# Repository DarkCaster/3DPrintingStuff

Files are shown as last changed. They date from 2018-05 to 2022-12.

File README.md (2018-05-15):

# My stuff for 3D printing

Projects (in subdirectories) use CC-BY-SA-4.0 license if not explicitly stated.

Directory layout:

### Anet_E10_X_BeltLock

Custom X-axis belt locks for better belt tensioning for Anet E10 3D-printer.
Please use ABS filament when printing it (or any other strong and durable material that will endure high static\dynamic stretching forces and high temperatures).
For use with this tensioning mechanism: https://www.thingiverse.com/thing:2482051

### NEMA17_GearedExtruderDrive

Simple NEMA17 geared bowden extruder drive with 6:1 gear ratio (work in progress).

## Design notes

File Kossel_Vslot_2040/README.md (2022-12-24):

Based on following work by Loong Jin Chow:
https://www.thingiverse.com/thing:749151

Changes:
- ported to newer MCAD version used in my repo
- fixed minor errors
- vslot screw-holes changed to M4, minor fix for motor screws
- top-corner updated to use M3 bolt with short thread for pulley axis

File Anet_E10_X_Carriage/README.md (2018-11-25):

# Improved X Carriage for Anet E10

Based on this drawing: https://www.thingiverse.com/thing:2833791

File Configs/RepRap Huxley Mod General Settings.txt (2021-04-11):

Printer Settings:

X: 163
Y: 167
Z: 115

Shape: Rect
X: Origin at center
V: Heated bed

//TODO: measure
Xmin: 25
Ymin: 45
Xmax: 35
Ymax: 20

GCODE Flavor: Marlin

Extruder 1:

Nozzle: 0.4
Material diameter: 1.75
Offsets: X=0, Y=0

//I: Skew factor = 0.0052805446815000160049047295274249
//J: Skew factor = -0.0013505025366120323223467769579997
//K: Skew factor = -0.0028104139251266379434524012026486
//M852 I0.00528054 J-0.0013505 K-0.00281041

M852 I0.001577 J0.000266 K-0.001529

Start GCODE (MBL):

M300 P200
M0 P300
M300 P200
M0 P300
M300 P200
M0 P300
M0 Check clearance!
G90 ;absolute positioning
G28 ;Home
M900 K0.5 ;set linear advance factor
M420 S1 ;enable bed-leveling
M420 Z0.75 ;enable and set z fade value
G92 E0 ;zero the extruded length
G1 F200 E10 ;extrude 10mm of feed stock
G92 E0 ;zero the extruded length again

End GCODE (MBL):

M104 S0 ;disable hotend heater
M140 S0 ;disable bed heater
G91 ;relative positioning
G1 E-3 F300 ;retract the filament a bit
G1 Z+5 E-3 X-20 Y-20 F6000 ;move Z up and retract filament even more
G90 ;absolute positioning
G28 X Y ;home the X and y axes
M84 ;steppers off
M420 Z0 ;disable bed-leveling z fade
M420 S0 ;disable bed-leveling

Start GCODE (UBL):

G90 ;absolute positioning
G28 ;Home
G29 A1 ;enable UBL
G29 L1 ;load UBL mesh 1
G29 F0.75 ;set UBL z fade value
G92 E0 ;zero the extruded length
G1 F200 E10 ;extrude 10mm of feed stock
G92 E0 ;zero the extruded length again

End GCODE (UBL):

M104 S0 ;disable hotend heater
M140 S0 ;disable bed heater
G91 ;relative positioning
G1 E-3 F300 ;retract the filament a bit
G1 Z+5 E-3 X-20 Y-20 F6000 ;move Z up and retract filament even more
G90 ;absolute positioning
G28 ;home
M84 ;steppers off
G29 A0 ;disable UBL

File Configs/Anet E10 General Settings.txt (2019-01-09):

Printer Settings:

X: 220
Y: 270
Z: 250 (300)

Shape: Rect
X: Origin at center
V: Heated bed

Xmin: 25
Ymin: 45
Xmax: 35
Ymax: 20

GCODE Flavor: Marlin

Extruder 1:

Nozzle: 0.4
Material diameter: 1.75
Offsets: X=0, Y=0

Skew correction
//M852 I-0.00125085 J0.00103114 K0.00283084
M852 I-0.00125085 J0.00210749 K0.00283084

Start GCODE:

G90 ;absolute positioning
G28 ;Home
M900 K0.5 ;set linear advance factor
M420 S1 ;enable bed-leveling
M420 Z0.75 ;enable and set z fade value
G1 Z15.0 F6000 ;Move the platform down 15mm
G92 E0 ;zero the extruded length
G1 F200 E10 ;extrude 10mm of feed stock
G92 E0 ;zero the extruded length again

End GCODE:

M104 S0 ;disable hotend heater
M140 S0 ;disable bed heater
G91 ;relative positioning
G1 E-3 F300 ;retract the filament a bit
G1 Z+5 E-3 X-20 Y-20 F6000 ;move Z up and retract filament even more
G90 ;absolute positioning
G28 X Y ;home the X and y axes
M84 ;steppers off
M420 Z0 ;disable bed-leveling z fade
M420 S0 ;disable bed-leveling

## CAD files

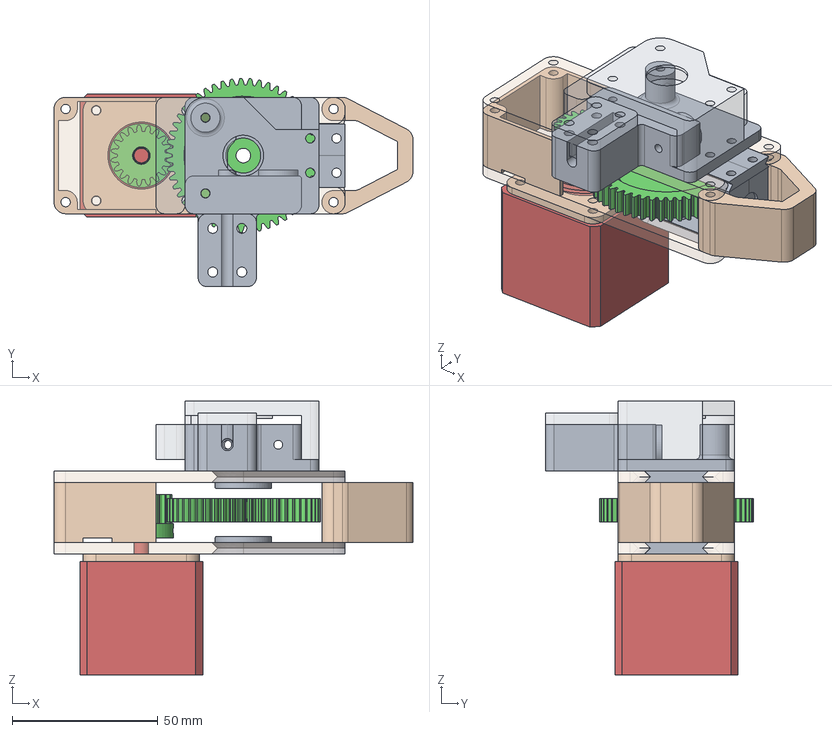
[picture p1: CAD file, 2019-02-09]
GearedExtruderDrive_V2/DriveAssembly_Variant1.FCStd
123.3 x 71.5 x 94.0 mm
FrameBottom
NEMA17Spacer
Nema17_Motor
FrontStand_H20.5mm
FrameTop
BackStand_H20.5mm
SmallGear_D5.4mm+M2.5
DriveBase_Tight_NoFitting
DriveBase_Fitting_Clamp
DriveIdler_623zz_Tight
DriveIdler_Cover_625zz
IdlerPart_625zz_Bottom
IdlerPart_625zz_Top
IdlerStand_H20.5mm
LargeGear_M5_H8mm_ClipH4.6mm_001

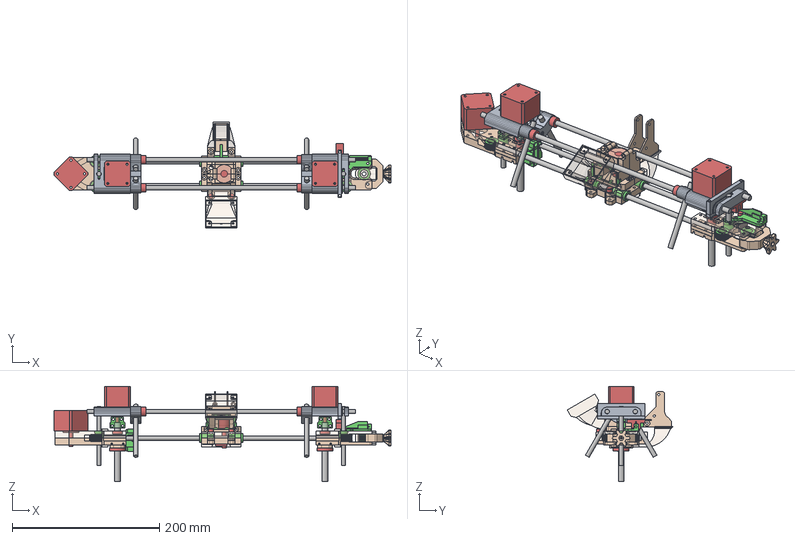
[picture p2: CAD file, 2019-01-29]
RepRap_Huxley_CustomParts/XZAxis_Assembly_A2PlusAddon.FCStd
457.6 x 143.3 x 129.0 mm
RightXEndHalf_Bottom
RightXEndHalf_Top
RightXEnd_TensionerStand
RightXEnd_TensionerKnob
RightXEnd_TensionerIdler
BeltPulley_2x685zz_FCGearAddon
Right_BeltPulley_2x623zz_FCGearAddon
Right_BeltPulley_2x623zz_FCGearAddon_Mirror
RightBearingClamp
RightZThreaderRodClip_THSL-200-8D
RightNut_THSL-200-8D
RightZBearing
BearingScrewTop
ZEndstopClip1
ZEndstopClip2
XRod_M6x320mm
XRod_M6x320mm_Mirror
LeftXEndHalf_Bottom
LeftXEndHalf_Top
Left_BeltPulley_2x623zz_FCGearAddon
Left_BeltPulley_2x623zz_FCGearAddon (Mirror #3)
LeftBearingClamp
LeftZThreaderRodClip_THSL-200-8D
LeftNut_THSL-200-8D
LeftZBearing
XMotor
XEndstopClip1
XEndstopClip2
XEndstopClip2_Mirror
XCarriageHalf_Bottom
XCarriageHalf_Top
XBearing
XBearing_Mirror1_YZ
XBearing_Mirror2_XZ
XBearing_Mirror1_XZ
XCarriageBeltClamp
XCarriageBeltClamp_Mirror
HotendClippingLeftHalf_E3DV6_Bowden
HotendClippingRightHalf_E3DV6_Bowden
Hotend_E3D_Dummy
Hotend_E3D_Dummy_Outer
ScrewTopCilinder1
ScrewTopCilinder2
HotendFrontFanCase_40x40
FrontFanCaseClip_40x40
BackClip
BackTurbineClip
BackTurbinePipe_TwoSides
RightMotorBracket
RightMotor
RightFrameVertex
RightTopRodNut
RightTopRodNut_Mirror
RightRod_M6x80mm
RightSideRod_M6x80mm
RightSideRod_M6x80mm_Mirror
RightZThreadedRodCoupler_THSL-200-8D
RightZThreadedRodCoupler_THSL-200-8D_Mirror
RightRod_M8x80mm
RightZEndStopClip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

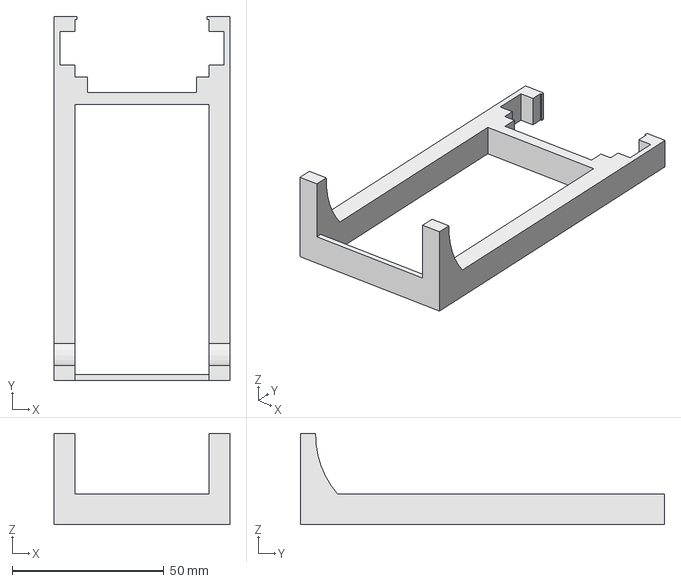
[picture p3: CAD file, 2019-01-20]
RepRap_Huxley_CustomParts/Other/XZAxisMaintenanceStand_Left.FCStd
58.0 x 120.0 x 30.0 mm

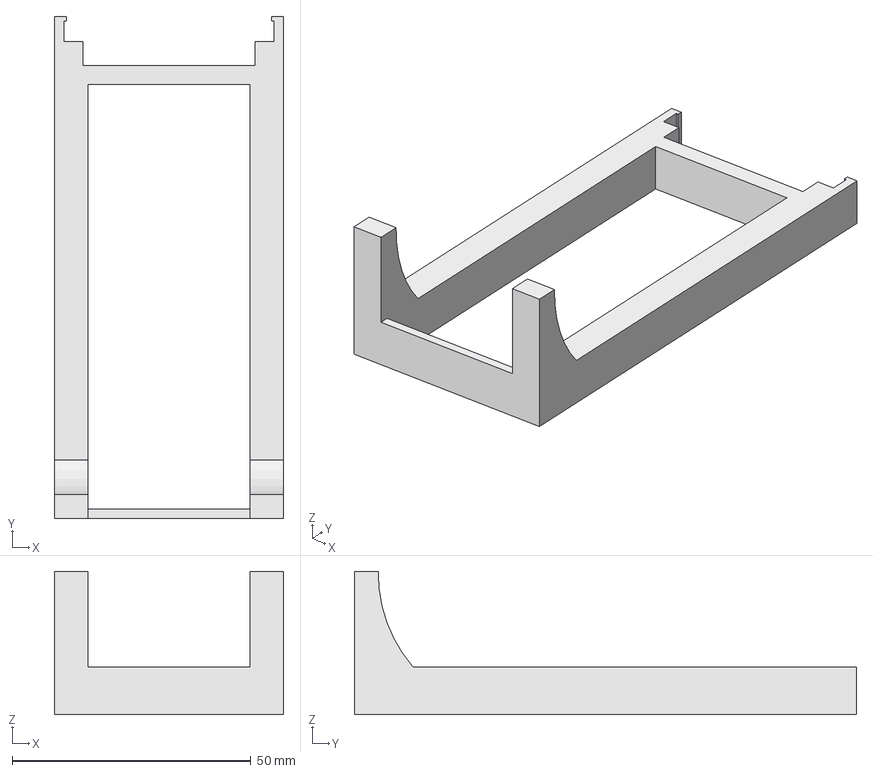
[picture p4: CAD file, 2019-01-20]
RepRap_Huxley_CustomParts/Other/XZAxisMaintenanceStand_Right.FCStd
48.0 x 105.3 x 30.0 mm

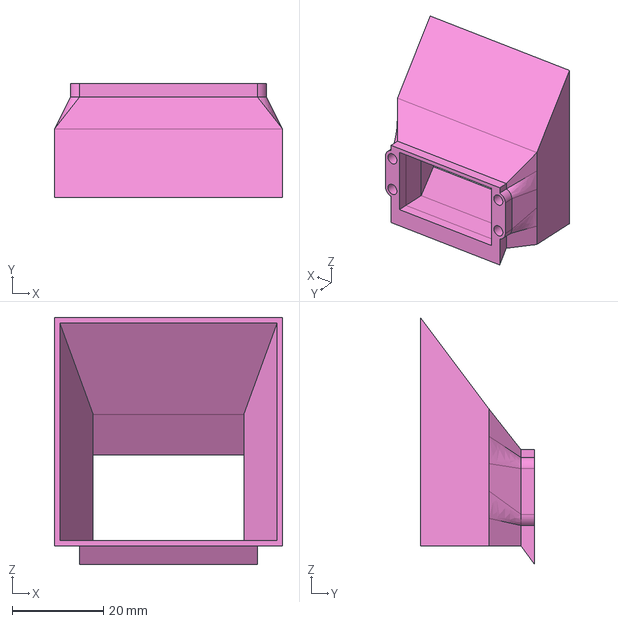
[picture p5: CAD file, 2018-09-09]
RepRap_Huxley_CustomParts/HotendClippingMainFan50x50.FCStd
50.0 x 25.0 x 54.1 mm

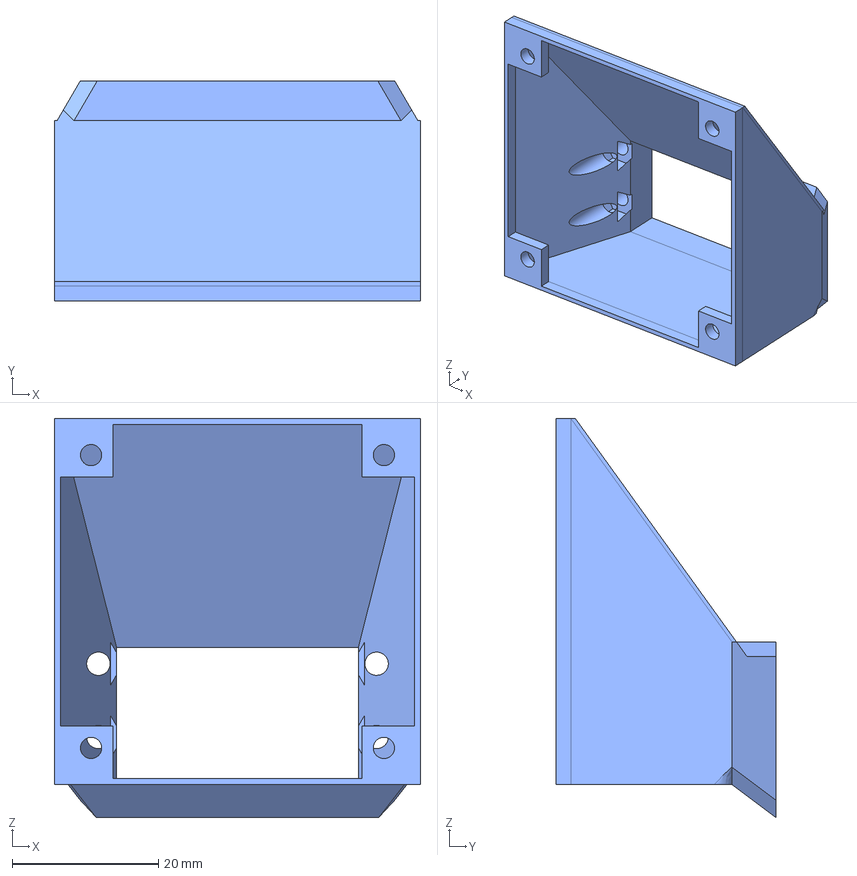
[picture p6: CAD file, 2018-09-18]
RepRap_Huxley_CustomParts/XCarriage/HotendClippingMainFan50x50.FCStd
50.0 x 30.0 x 54.5 mm

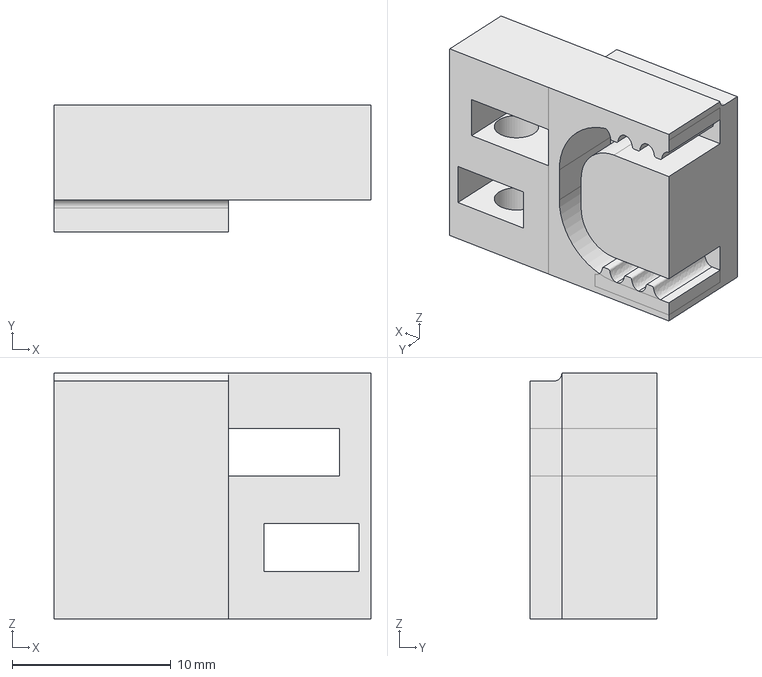
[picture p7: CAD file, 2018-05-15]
Anet_E10_X_BeltLock/LeftBeltLock.FCStd
20.0 x 8.00 x 15.5 mm

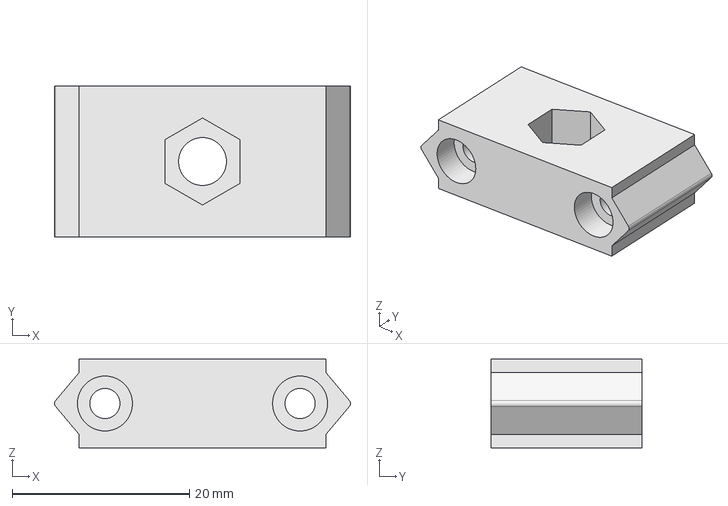
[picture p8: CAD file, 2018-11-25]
Anet_E10_X_Carriage/XCarriageBottomWheel.fcstd
33.4 x 17.0 x 10.0 mm

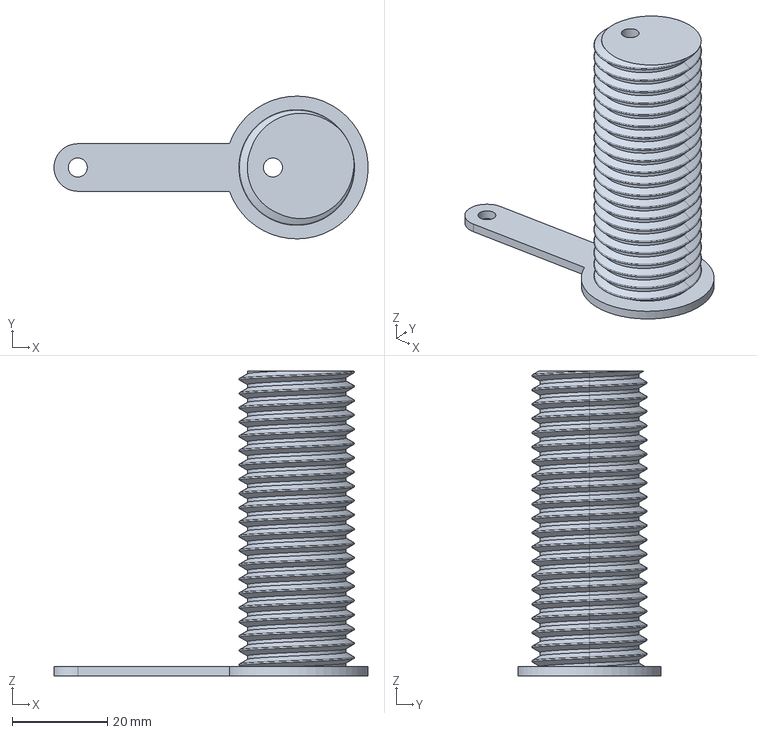
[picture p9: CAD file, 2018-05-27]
Anet_E10_Z_Counterweight/CounterweightBase_M24+M4.FCStd
66.0 x 30.0 x 64.0 mm

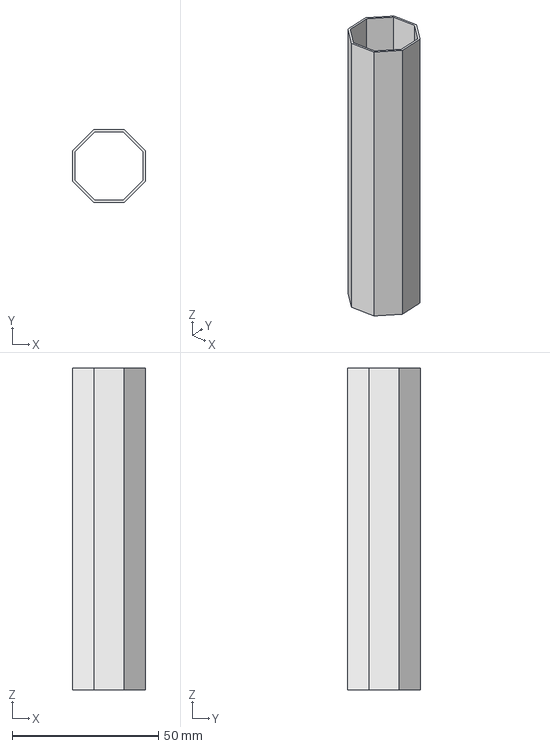
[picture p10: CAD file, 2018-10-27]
CalibrationSquare/ZPillar.fcstd
25.0 x 25.0 x 110.0 mm

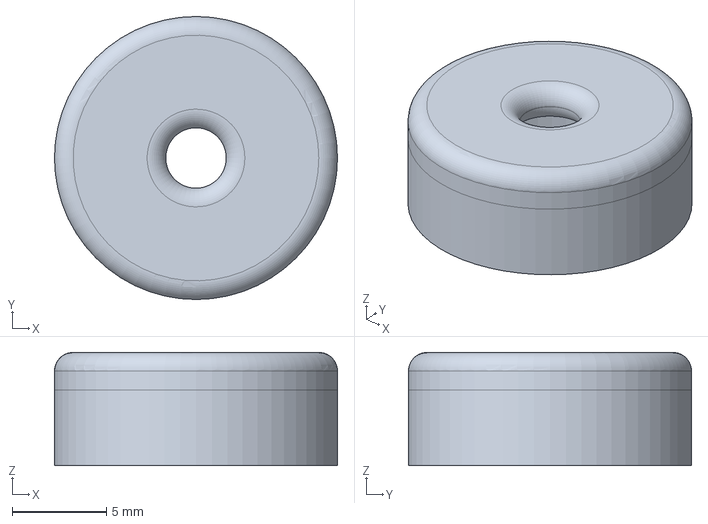
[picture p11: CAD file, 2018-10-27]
FilamentFilter/Cap.FCStd
15.0 x 15.0 x 6.00 mm

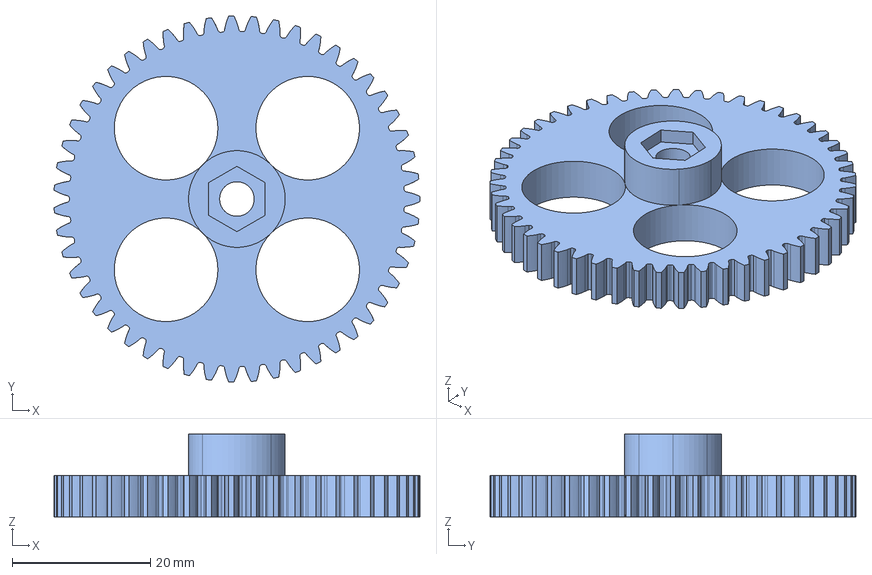
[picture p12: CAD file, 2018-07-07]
GearedExtruderDrive_V1_NEMA17/LargeGear_V2_ABS_M5.FCStd
53.0 x 53.0 x 12.0 mm

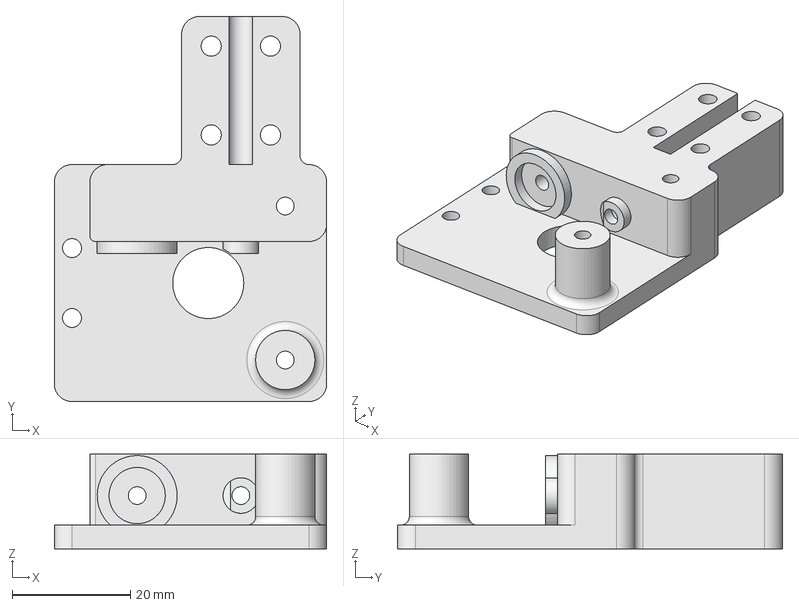
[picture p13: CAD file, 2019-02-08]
GearedExtruderDrive_V2/DriveBase/DriveBase_Tight_NoFitting.FCStd
46.0 x 65.0 x 16.0 mm

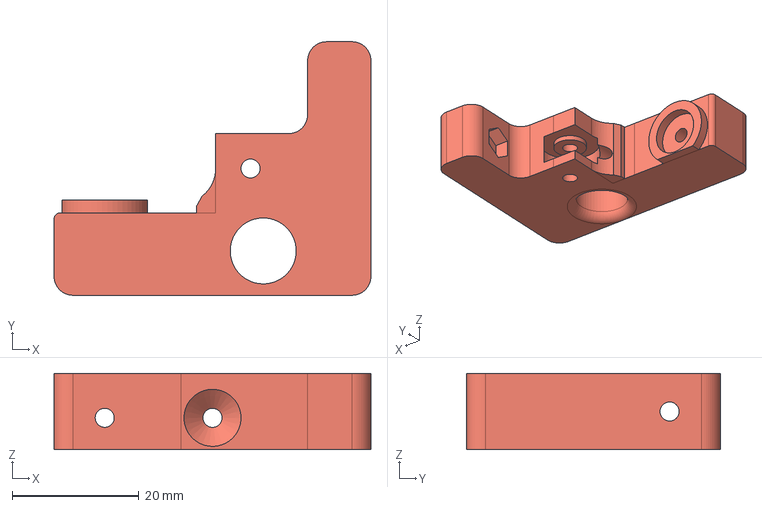
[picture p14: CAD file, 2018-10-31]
GearedExtruderDrive_V2/DriveIdler/DriveIdler_623zz_Tight.FCStd
50.0 x 40.0 x 12.0 mm

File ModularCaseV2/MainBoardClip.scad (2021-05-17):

use <../OpenSCAD_Modules/cube_vround.scad>

module NylonTieCut
(
//tie
	tieHeight=4.5,
	tieWidth=1.5,
	tieDepth=5,
	tieShift=5,
//lock cut
	cutShift=2.5,
	cutHeight=7,
	cutDepth=100,
)
{
	cutClr=0.1;
	union()
	{
		translate([0,0,tieHeight/2])
		{
			translate([tieShift,-cutClr,-tieHeight/2])
				cube([tieWidth,tieDepth+2*cutClr,tieHeight]);
			translate([-cutClr,tieDepth,-cutHeight/2])
				cube([cutClr+tieShift+tieWidth+cutShift,cutDepth,cutHeight]);
		}
	}
}

module MBClip
(
	height=11,
	width=25,
	depth=25,
	cornerCutR=6/2,
	screwHoleX=10,
	screwHoleD=3.5,
	cutX=11,
	cutY=10,
	cutD=2,
	cutXShift=1,
	quality=1,
)
{
	tieHeight=4.5;
	cutClr=0.1;
	difference()
	{
		//case base
		cube_vround(size=[width,depth,height],rounding=2,quality=quality,round_corners=[false,false,false,true]);
		//corner rod cut
		translate([0,0,-cutClr])
			cylinder(h=height+2*cutClr,r=cornerCutR,$fn=24*quality);
		translate([0,0,(height-tieHeight)/2])
			NylonTieCut(tieHeight=tieHeight);
		translate([cutX,-cutY,-cutClr])
			cube_vround(size=[width,depth,height+cutClr*2],rounding=2,quality=quality,round_corners=[false,false,false,true]);
		translate([cutX,(depth-cutY)+cutY/2-cutD/2,-cutClr])
			cube_vround(size=[width,cutD,height+cutClr*2],rounding=cutD/2,quality=quality,round_corners=[false,false,true,true]);
		translate([(width-cutX)+cutX/2-screwHoleD/2+cutXShift,-cutClr,height/2])
			rotate(a=90,v=[-1,0,0])
				cylinder(h=depth+2*cutClr,d=screwHoleD,$fn=24*quality);
	}

}

MBClip();

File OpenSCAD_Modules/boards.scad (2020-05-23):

module board(
	size_x=50,
	size_y=50,
	width=1.5,
	hole_diam=3,
	rounding=1,
	hole1=[3,3],
	hole2=[3,3],
	hole3=[3,3],
	hole4=[3,3],
	center_xy=false,
	center_z=false,
	board_color=[0.3,0.5,0.3],
	quality=2, //integer from 1 to infinity
)
{
	assert(size_x>0);
	assert(size_y>0);
	assert(width>0);
	assert(hole_diam>0);
	assert(rounding>0);
	assert(rounding<=size_x/2);
	assert(rounding<=size_y/2);
	assert(quality>0)

	color(board_color)
		translate([center_xy?-size_x/2:0,center_xy?-size_y/2:0,center_z?-width/2:0])
			difference()
			{
				//base
				translate([rounding,rounding])
					resize([size_x,size_y,width])
						minkowski()
						{
							cube([size_x-rounding*2,size_y-rounding*2,width]);
							cylinder(r=rounding,h=width,$fn=12*quality);
						};
				//holes
				if(hole1!=false && len(hole1)==2)
					translate([hole1[0],hole1[1],-width/2])
						cylinder(r=hole_diam/2,h=width*2,$fn=12*quality);
				if(hole2!=false && len(hole2)==2)
					translate([size_x-hole2[0],hole2[1],-width/2])
						cylinder(r=hole_diam/2,h=width*2,$fn=12*quality);
				if(hole3!=false && len(hole3)==2)
					translate([size_x-hole3[0],size_y-hole3[1],-width/2])
						cylinder(r=hole_diam/2,h=width*2,$fn=12*quality);
				if(hole4!=false && len(hole4)==2)
					translate([hole4[0],size_y-hole4[1],-width/2])
						cylinder(r=hole_diam/2,h=width*2,$fn=12*quality);
			}
}

//example
board(size_x=30,size_y=80,hole1=[15,3],hole2=false,center_xy=true,center_z=true,rounding=3);

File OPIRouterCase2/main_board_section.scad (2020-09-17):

use <../OpenSCAD_Modules/case_section.scad>
use <../OpenSCAD_Modules/cube_vround.scad>
use <../OpenSCAD_Modules/stand.scad>

mainboard_size=[99,143,35.5];

function mainboard_height(base_sz=2,mainboard_clearance=1) = base_sz+mainboard_size[2]+mainboard_clearance/2;

module mainboard_section(
size=[112,160],
screw_diam=3,
screw_clearance=0.2,
wall_sz=1.6,
base_sz=2,
center_xy=false,
center_z=false,
attach=0,
quality=2,
vent_size=[10,2],
vent_period=[20,5],
vent_angle=45,
mainboard_clearance=1,
cable_diam=6.75,
antenna_diam=6.5,
antenna_z=25,
antenna_x=15,
clip_z=10,
clip_int_sz=3,
clip_ext_sz=10,
clip_width=3,
clip_clearance=0.2,
clip_cover_width=3+1.6,
clip_cover_sz=12,
rear_cut_z=20,
rear_cut_x=100,
rear_cut_depth=15,
rear_cut_clip_x=2,
rear_cut_clip_z=10,
rear_cut_clip_shift=5,
)
{
	attach_clearance=0.05;
	psu_clr_mode=mainboard_size[0]>mainboard_size[1];
	psu_screw_dy=18;
	psu_screw_diam=3;
	psu_screw_ext_diam=5;
	psu_screw_dx1=6.5;
	psu_screw_dx2=80.5;
	psu_cable_ext_diam=cable_diam+2;
	psu_cable_pos_y=psu_screw_dy;
	assert(len(size)==2);
	size_x=size[0];
	size_y=size[1];
	height=mainboard_height(base_sz=base_sz,mainboard_clearance=mainboard_clearance);
	assert(screw_diam>1);
	assert(screw_diam<=6);
	assert(attach>=0);
	max_subsz=mainboard_size[1];
	max_wallsz=wall_sz;
	min_szx=max_wallsz+wall_sz+2*(psu_clr_mode?mainboard_clearance:screw_diam+wall_sz)+mainboard_size[0];
	min_szy=2*(wall_sz+(psu_clr_mode?screw_diam+wall_sz:mainboard_clearance))+max_subsz;
	psu_stand_sz=psu_clr_mode?(size_y-mainboard_size[1]-2*wall_sz)/2:mainboard_clearance;
	assert(size_x>=min_szx);
	assert(size_y>=min_szy);
	psu_mvx=size_x/2-mainboard_size[0]/2-(psu_clr_mode?mainboard_clearance:screw_diam+wall_sz)-wall_sz;
	psu_cable_mvx=(size_x-mainboard_size[0])/2+4;
	translate([center_xy?0:size_x/2,center_xy?0:size_y/2,center_z?-height/2:0])
	{
		difference()
		{
			union()
			{
				//case section
				case_section(size=[size_x,size_y,height],
					screw_diam=screw_diam,
					screw_clearance=screw_clearance,
					wall_sz=wall_sz,
					base_sz=base_sz,
					attach=attach,
					quality=quality,
					vents=[true,false,false,true],
					vent_size=vent_size,
					vent_period=vent_period,
					vent_angle=vent_angle,
					center_xy=true);
				translate([0,-size_y/2,clip_z])
					rotate(a=90,v=[0,1,0])
						linear_extrude(height=size_x-wall_sz*4-screw_diam, center = true)
							polygon(points = [[-clip_cover_sz/2,0],[-clip_cover_sz/2,clip_cover_width],[clip_cover_sz/2,clip_cover_width],[clip_cover_sz/2,0]]);
			}
			translate([-size_x/2+psu_cable_mvx+wall_sz,-(size_y-wall_sz)/2,psu_screw_dy+base_sz])
				rotate(a=90,v=[1,0,0])
					cylinder(d=cable_diam,h=wall_sz+attach_clearance,center=true,$fn=12*quality);
			translate([0,-size_y/2,clip_z])
				rotate(a=90,v=[0,1,0])
					linear_extrude(height=size_x*2, center = true)
						polygon(points = [[-clip_int_sz/2-clip_clearance,-attach_clearance],[-clip_ext_sz/2-clip_clearance,clip_width],[clip_ext_sz/2+clip_clearance,clip_width],[clip_int_sz/2+clip_clearance,-attach_clearance]]);
			//antenna
			translate([size_x/2-wall_sz/2,-size_y/2+antenna_x,antenna_z+base_sz])
				rotate(a=90,v=[0,1,0])
					cylinder(d=antenna_diam,h=wall_sz+attach_clearance*2,center=true,$fn=12*quality);
			translate([size_x/2-wall_sz/2,size_y/2-antenna_x,antenna_z+base_sz])
				rotate(a=90,v=[0,1,0])
					cylinder(d=antenna_diam,h=wall_sz+attach_clearance*2,center=true,$fn=12*quality);
			//rear cut
			translate([size_x/2-rear_cut_depth,-rear_cut_x/2,0-attach_clearance])
				cube(size=[rear_cut_depth+attach_clearance,rear_cut_x,rear_cut_z+attach_clearance]);
			translate([size_x/2-rear_cut_depth,-rear_cut_x/2-rear_cut_clip_x-rear_cut_clip_shift,rear_cut_clip_z])
				cube(size=[rear_cut_depth+attach_clearance,rear_cut_clip_x,rear_cut_clip_z]);
			translate([size_x/2-rear_cut_depth,rear_cut_x/2+rear_cut_clip_shift,rear_cut_clip_z])
				cube(size=[rear_cut_depth+attach_clearance,rear_cut_clip_x,rear_cut_clip_z]);
		}
		//draw psu box
		if($preview)
			color([0.75,0.75,0.75])
			translate([psu_mvx,0,mainboard_size[2]/2+base_sz])
				cube(size=mainboard_size,center=true);
	}
}

mainboard_section(center_xy=true,center_z=true);

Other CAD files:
GearedExtruderDrive_V2/DriveIdler_Top/DriveIdler_Cover_625zz.FCStd
GearedExtruderDrive_V2/Frame/FrameTop.FCStd
GearedExtruderDrive_V2/Helpers/Nema17_Motor.FCStd
GearedExtruderDrive_V2/LargeGearAssembly/LargeGear_M5_ClipH5.6mm.FCStd
Kossel_Vslot_Carriage/WheelCarriage.scad
2x5.25in_To_3x3.5in_Hdd_Adapter/FrontStand.scad
2x5.25in_To_3x3.5in_Hdd_Adapter/RearStand.scad
Anet_E10_X_BeltLock/RightBeltLock.FCStd
Anet_E10_X_Carriage/XCarriage.fcstd
CalibrationSquare/VerticalSquare.FCStd
CalibrationSquare/VerticalSquare_Fusion.FCStd
ChandelierClipAdapter/AdapterParts.scad
ChandelierClipAdapter/AdapterPartsAlt.scad
Custom3DPrinterBedPlate/plate.scad
Custom3DPrinterBedPlate/plate_v2.scad
Custom3DPrinterBedPlate/plate_v3.scad
FanCovers/FanCover1.scad
FanCovers/FanCover2.scad
FilamentFilter/Box.FCStd
GearedExtruderDrive_V1_NEMA17/Base_623zz+M3.FCStd
GearedExtruderDrive_V1_NEMA17/Base_685zz+M3.FCStd
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

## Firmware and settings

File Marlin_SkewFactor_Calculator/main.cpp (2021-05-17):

#include <iostream>
#include <iomanip>
#include <cmath>

// ******* define measured values here
// ******* for better accuracy all values should be measured multiple times

//xy

//const double AC_values[] = {141.18, 141.18, 141.18, 141.18};
//const double BD_values[] = {140.95, 140.96, 140.96, 140.96};
//const double AD_values[] = {100.02, 100.02, 100.02, 100.02};

//xz

//const double AC_values[] = {112.95, 112.96, 112.96, 112.95};
//const double BD_values[] = {112.92, 112.93, 112.93, 112.92};
//const double AD_values[] = {79.82, 79.84, 79.85, 79.82};

//yz
const double AC_values[] = {112.72, 112.74, 112.72, 112.75};
const double BD_values[] = {112.94, 112.94, 112.86, 112.88};
const double AD_values[] = {79.92, 79.86, 79.88, 79.88};

// *******
// *******

template <typename T, int N>
constexpr int ConstArraySize (T (&target)[N]) { return sizeof(target)/sizeof(target[0]); }

template <typename T, int N>
constexpr T ConstAverage (T (&target)[N])
{
  int arraySize=ConstArraySize(target);
  auto average=target[0];
  for(int i=1; i<arraySize; ++i)
    average+=(target[i]-average)/(T)(i+1);
  return average;
}

const double AC=ConstAverage(AC_values);
const double BD=ConstAverage(BD_values);
const double AD=ConstAverage(AD_values);

int main(void)
{
  auto AB=sqrt(2.0*AC*AC+2.0*BD*BD-4.0*AD*AD)/2.0;
  auto skewFactor=tan(M_PI_2-acos((AC*AC-AB*AB-AD*AD)/(2.0*AB*AD)));
  std::cout << "Skew factor = " << std::setprecision (32) << skewFactor << std::endl;
  return 0;
}

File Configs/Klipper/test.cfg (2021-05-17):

[mcu]
serial: /tmp/ttyETH3

[printer]
kinematics: cartesian
max_velocity: 100
max_accel: 3000
max_z_velocity: 25
max_z_accel: 30

[stepper_x]
step_pin: PD4
dir_pin: PD5
enable_pin: !PD6
microsteps: 16
rotation_distance: 40
endstop_pin: ^PD7
position_endstop: 0
position_max: 200

[stepper_y]
step_pin: PB0
dir_pin: PB1
enable_pin: !PB2
microsteps: 16
rotation_distance: 40
endstop_pin: ^PB3
position_endstop: 0
position_max: 200

[stepper_z]
step_pin: PC0
dir_pin: PC1
enable_pin: !PC2
microsteps: 16
rotation_distance: 8
endstop_pin: ^PC3
position_endstop: 0.5
position_max: 200

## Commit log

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2018-05-15 Anet_E10_X_BeltLock: added initial RightBeltLock.FCStd
    [RightBeltLock.FCStd]
2018-05-15 Anet_E10_X_BeltLock: LeftBeltLock.FCStd updated, make it more "slim", reinforce clamp, mirror part against XZ plane - it should not interfere with X endstop switch anymore
    [LeftBeltLock.FCStd]
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2018-05-15 Anet_E10_X_BeltLock: LeftBeltLock.FCStd updated - make it shorter, so it will fit even bettter
    [LeftBeltLock.FCStd]
2018-05-15 NEMA17_GearedExtruderDrive: added initial drawings - LargeGear_M3.FCStd and SmallGear_D5mm+M3.FCStd
    [LargeGear_M3.FCStd, SmallGear_D5mm+M3.FCStd]
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2018-05-16 NEMA17_GearedExtruderDrive: Idler_623zz+M4.FCStd updated - added clamp for bearing
    [Idler_623zz+M4.FCStd]
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2018-05-21 NEMA17_GearedExtruderDrive: Idler_623zz+M3.FCStd updated, fix bearing-notch size
    [Idler_623zz+M3.FCStd]
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2018-06-12 NEMA17_GearedExtruderDrive: Base_685zz+M3.FCStd updated, added window (pocket) for filament-pulley's nut
    [Base_685zz+M3.FCStd]
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2018-06-16 NEMA17_GearedExtruderDrive: LargeGear_M5.FCStd renamed to LargeGear_ABS_M5.FCStd, nut pocket diameter updated
    [LargeGear_ABS_M5.FCStd, LargeGear_M5.FCStd]
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2018-07-07 NEMA17_GearedExtruderDrive: added new versions of LargeGear and SmallGear drawings, using 19/15 ratio and odd teeth count
    [LargeGear_V2_ABS_M5.FCStd, SmallGear_V2_ABS_D5.2mm+M3.FCStd]
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2018-12-28 RepRap_Huxley_CustomParts: move parts for right x-axis end assembly to XAxis_Right subdir
    [BeltPulley_2x685zz_FCGear.FCStd, RightXEndHalf2_Alt1.FCStd, RightXEndHalf_Alt1.FCStd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]
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2018-12-28 RepRap_Huxley_CustomParts: added XAxis_Assembly_A2PlusAddon.fcstd drawing - assembly for x-axis parts, using A2Plus addon
    [XAxis_Assembly_A2PlusAddon.fcstd]
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2018-12-29 RepRap_Huxley_CustomParts: move parts for left x-axis end assembly to XAxis_Left subdir
    [LeftXEndHalf2_Alt1.fcstd, LeftXEndHalf_Alt1.fcstd]
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2018-12-29 fixup! RepRap_Huxley_CustomParts/XAxis_Left: top-frame and bottom-frame parts renamed
    [LeftXEndHalf_Bottom.FCStd, LeftXEndHalf_Top.FCStd]
2018-12-29 Added RepRap_Huxley_CustomParts/Helpers/Rod_M6x320mm.FCStd drawing (helper model for use within assembly)
    [Rod_M6x320mm.FCStd]
2018-12-29 RepRap_Huxley_CustomParts: move parts for hotend carriage assembly to XCarriage subdir
    [CarriageBeltClamp.FCStd, CarriageHalf_Bottom.FCStd, CarriageHalf_Top.FCStd]
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2019-01-02 RepRap_Huxley_CustomParts: move parts for hotend assembly to XCarriage subdir
    [HotendClippingExtraFanTurbine.FCStd, HotendClippingLeftHalf_E3DV6_Bowden.FCStd, HotendClippingMainFan50x50.FCStd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]
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2019-01-02 RepRap_Huxley_CustomParts/XCarriage: hotend clipping drawings (left and right half) updated (work in progress)
    [HotendClippingLeftHalf_E3DV6_Bowden.FCStd, HotendClippingRightHalf_E3DV6_Bowden.FCStd]
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2019-01-14 RepRap_Huxley_CustomParts: move extruder drive holder related parts to "ExtruderDriveHolder" dir
    [ExtruderDriveHolder1_Alt.FCStd, ExtruderDriveHolder2_Alt.FCStd, ExtruderDriveHolder3_Alt.FCStd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]
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2019-01-20 fixup! Added RepRap_Huxley_CustomParts/Other/XZAxisMaintenanceStand_Right.FCStd drawing
    [XZAxisMaintenanceStand_Right.FCStd]
2019-01-20 fixup! Added RepRap_Huxley_CustomParts/Other/XZAxisMaintenanceStand_Left.FCStd drawing
    [XZAxisMaintenanceStand_Left.FCStd]
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2019-08-06 Added ModularCase/CaseAssembly.FCStd assembly drawing, added timestamp save/restore script
    [CaseAssembly.FCStd, HBlock1Half.FCStd]
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2019-08-20 ModularCase: added drawings for various internal components, case assembly updated
    [ArduinoMegaWithRamps.FCStd, CaseAssembly.FCStd, PSU.FCStd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]
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2019-08-28 ModularCase: case assembly updated, HBlock2_1_Alt and PSU drawings updated
    [CaseAssembly.FCStd, HBlock2_1_Alt.FCStd, PSU_ALT.FCStd]
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2019-08-28 fixup! ModularCase: case assembly updated, HBlock2_1_Alt drawing updated
    [CaseAssembly.FCStd, HBlock2_1_Alt.FCStd]
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2019-10-30 ModularCase: case assembly updated, added EC5Clip1.FCStd and EC5Clip2.FCStd drawings
    [CaseAssembly.FCStd, EC5Clip1.FCStd, EC5Clip2.FCStd]
2019-10-30 ModularCase: case assembly updated, added XT60+XT30Clip1.FCStd and XT60+XT30Clip2.FCStd drawings
    [CaseAssembly.FCStd, XT60+XT30Clip1.FCStd, XT60+XT30Clip2.FCStd]
2019-11-07 ModularCase: case assembly updated, added top and bottom case-locks drawings
    [BottomLockHalf.FCStd, CaseAssembly.FCStd, TopLockHalf.FCStd]
2019-11-11 ModularCase: case assembly updated, top case-lock drawing updated
    [CaseAssembly.FCStd, TopLockHalf.FCStd]
2019-11-11 ModularCase: case assembly updated, bottom case-lock drawing updated
    [BottomLockHalf.FCStd, CaseAssembly.FCStd]
2019-11-12 ModularCase: case assembly updated, added corner stand drawing
    [CaseAssembly.FCStd, CornerStand.FCStd]
2019-11-13 ModularCase: case assembly updated, corner stand drawing updated
    [CaseAssembly.FCStd, CornerStand.FCStd]
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2019-11-14 ModularCase: case assembly updated, added some optional parts
    [CaseAssembly.FCStd, DisplayClipHalf.FCStd, DisplayClipHalf_Mirrored.FCStd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]
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2019-12-04 ModularCase: case assembly updated, top handle drawing updated
    [CaseAssembly.FCStd, TopHandle.FCStd]
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2020-07-20 fixup! Added 2x5.25in_To_3x3.5in_Hdd_Adapter/FrontStand.scad OpenSCAD module
    [FrontStand.scad]
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2020-07-25 fixup! Added FanCovers/FanCover1.scad OpenSCAD module
    [FanCover1.scad]
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2020-07-26 fixup! Added Other/2.5in_hdd_clip1.scad OpenSCAD module
    [2.5in_hdd_clip1.scad]
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2020-07-28 fixup! Added 2x5.25in_To_3x3.5in_Hdd_Adapter/RearStand.scad OpenSCAD module
    [RearStand.scad]
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2020-12-19 Other: added ngff-sata adapter to 3.5 hdd stand
    [3.5in_hdd_stand_for_ngff_adapter.scad, 3.5in_ngff_adapter_bracket.scad]
2020-12-20 fixup! Other: added ngff-sata adapter to 3.5 hdd stand
    [3.5in_hdd_stand_for_ngff_adapter.scad]
2020-12-20 Other: added D3.5 mm washer and 7mm-height stand models
    [7mm_stand.scad, washer_D3.5mm.scad]
2020-12-20 fixup! Other: added D3.5 mm washer and 7mm-height stand models
    [stand_cyl.scad]
2021-04-11 Added PTFETubeClip/PTFEClip.scad drawing: yet anothe clip for PTFE tube, compatible with BMG extruder drive and clones
    [PTFEClip.scad]
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2022-07-07 Breezer: update various tolerances
    [AirGate.scad, CaseCover1.scad]
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2022-12-20 Kossel Vslot 2040: update vslot clip hole-size to M4, minor fixes to motor mount
    [frame.scad]
2022-12-24 Kossel Vslot 2040: top_corner updated to use M3 bold with shorter thread
    [frame.scad]
2022-12-24 fixup! Kossel Vslot 2040: top_corner updated to use M3 bold with shorter thread
    [frame.scad]
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2024-11-17 Breezer/AurGate.scad updated - add extra stub layer (default to 0.2) to GateClip2
    [AirGate.scad]
2024-11-17 Breezer/AurGate.scad updated - add extra stub layer (default to 0.2) to GateBase
    [AirGate.scad]
2024-11-17 Breezer/WallTube.scad updated, add stub_layer_width parameter - extra thin stub layer at bottom that hides hole features from printing
    [WallTube.scad]
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2025-04-03 Breezer: remove drawings, not it's maintained in a separate project
    [AirGate.scad, Assembly1.scad, CaseCover1.scad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]
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2025-04-20 fixup! Added ChandelierClipAdapter drafts
    [AdapterParts.scad]
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2026-07-02 fixup! Added draft Other/WallExhaustMount.scad
    [WallExhaustMount.scad]
